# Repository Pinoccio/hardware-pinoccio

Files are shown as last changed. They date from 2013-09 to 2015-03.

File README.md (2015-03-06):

pinoccio-hardware-reference
===========================

Contained are the schematics, board layout, data sheets, and BOM for the
Pinoccio board. The firmware directory also has code for the 16u2 chip
on the board and the booloader running in the main MCU.

For the firmware, the branches contain only the source files. The
compiled versions used in production can be found in the tagged
revisions only.

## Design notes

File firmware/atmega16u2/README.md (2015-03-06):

Pinoccio 16u2 firmware
----------------------

To compile, go into lufa-100807/Projects/arduino-usbserial and run
`make`.

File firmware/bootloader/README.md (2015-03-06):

Pinoccio bootloader
===================
To compile, make sure that you have avr-gcc and friends in your path and
run:

	$ make

This should compile the uracoli lib (for radio / OTA updating) and the
main bootloader. The produced bootloader.hex can be uploaded through
avrdude normally, or through the IDE by putting it in the right place
(see boards.txt for the filename to use).

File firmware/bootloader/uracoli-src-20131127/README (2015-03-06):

This is the uracoli source code package. It contains
the following files:

- +src/+
  Source code of radio and ioutil library.
- +inc/+
  The header files for the libraries.
- +xmpl/+
  Some example applications, that illustrate how to use
  the µracoli functions.
- +wuart+
  The wireless UART application.
- +wibo/+
  The wireless bootloader framework, host application and
  examples.
- +sniffer/+
  The source code of the IEEE 802.15.4 sniffer firmware.
- +doc/+
  User documentation.
- +LICENSE+
  A copy of the uracoli license terms.
- +RELEASENOTES+
  Release history.

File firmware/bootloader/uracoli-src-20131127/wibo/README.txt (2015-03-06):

= WiBo - The Wireless Bootloader  =
:author: Daniel Thiele, Axel Wachtler
:date: 2010/07 - 2012/11
:toc: 1

== Abstract ==

The following article describes the usage of the uracoli wireless bootloader.
WiBo works like a regular bootloader, except that it uses the radio transceiver
instead of a UART. WiBo modifies the flash directly, therefore no special
backup flash memory, like in other over the air upgrade (OTA) solutions,
is required on the transceiver board.

== Concept ==

The WiBo framework provides a method to program the MCU that controls the
transceiver.
Three components are involved,

 * a PC with USB or serial interface, running the  script wibohost.py,
 * a host node, running with the wibohost firmware and
 * the network nodes that have the bootloader installed.

The python script +wibohost.py+ sends a hexfile +app.hex+ in slices
to the host node. It transmits these data slices as unicast or
broadcast frames to the network nodes. The network nodes collect
the data slices and programm them with SPM (self programming mode)
commands in the flash application section of the microcontroller.

In order to verfify if a node was programmed correctly, the
host and network nodes calculate a CRC16 during the transmission and
reception of the data slices.
When programming is completed, the wibohost can query the CRC
from the nodes and compare with its own checksum.

["ditaa"]
---------------------------------------------------------------------
                                             ^
  +------------------+                       | +---------+
  |   +---------+    |                       +-+ Node #1 |
  |   | app.hex |    |                         +---------+
  |   |      {d}|    |         +------+  ^
  |   +---------+    |         | WiBo |  |     ^
  |       |          |    +----* Host +--+     | +---------+
  |       v          |    |    | Node |        +-+ Node #2 |
  | /-------------+  |    |    +------+          +---------+
  | | wibohost.py |->*----+
  | |             |  | serial IF                ^
  | +-------------+  |                          | +---------+
  |                  |                          +-+ Node #3 |
  |                  |                            +---------+
  |       PC         |
  |                  |                        ^
  |                  |                        | +---------+
  +------------------+                        +-+ Node #N |
                                                +---------+
---------------------------------------------------------------------

The bootloading can be done either in *unicast* mode or in *broadcast* mode.
In unicast mode one node is programmed with a program image at one time. In
broadcast mode, multiple nodes receive the image in parallel. This is useful for
programming multiple instances of identical hardware with a firmware image.

.The host site
consists of a http://www.python.org[Python] script and the host node that runs
the wibohost firmware. The script +wibohost.py+ uses the module
http://pyserial.sourceforge.net[pyserial] for serial communication with the host
node. It reads and parses the given hex file and transfers it in slices to the
host node. The host node firmware sends this slices in frames to one (unicast)
or all (broadcast) network nodes.

.The wireless bootloader
resides in bootloader section of the network nodes and occupy about 1K words of
programm memory. Additionally to the bootloader code, configuration record at
the end of the bootloader section. This record ensures that the node address and
channel information is available, even if the EEPROM was accidentely erased.

The network nodes are passive, that means they never send anything if not
queried by the host node.

== Radio Configuration ==

Before the Atmel radio transceivers can be used in a wireless network szenario,
they need to be configured with some key parameters.

The most important parameter is the radio channel, e.g. the frequency on which
the radios communicate. Depending of the radio type, the cannel can be 11 - 26
for the 2.4GHz radios and 0 - 10 for the 868/900 MHz radios. Which channel to
choose depends on the area where the network is operated (for 868/900 MHz) and
which other interferers are present (e.g. Bluetooth and WLAN for 2.4GHz). Since
this topic can't be covered here complete, consult other information sources for
selecting a radio channel to operate on.

Other important parameters are the node address and the network address.
The IEEE-802.15.4 radios support a 16 bit (SHORT-ADDRESS) and a 64 bit
(IEEE-ADDRESS) node address as well as a 16 bit network identifier (PAN-ID).

Since for bootloaders with the limited amount of programm memory no complex
search and asociation procedures can be implemented, the channel and addressing
parameters needs to be stored persistently in the Flash or EEPROM memory of the
network node.

Since the EEPROM in AVR controllers can be easily erased or modified by the
application, a safe place to store  the radio configuration is the flash memory
(the programm memory itself). Since the parameters should be accessible from the
bootloader and from the final application, a so called configuration record is
stored at the end of the flash memory.

In order to create the config record at the flash end, a Intel Hex file needs to
be generated, that is flashed with the hardware programmer and .e.g. with the
tool avrdude.

For generating config records for multiple nodes, the pythonscript +wibo/nodeaddr.py+
is used. Basically the tool can be used directly on the command line.

------
$python wibo/nodeaddr.py -B rdk230 -c 17 -a 1 -A 0x1234567890ABCDEF -p 0xcafe -o foo.hex
Use Parameters:
 board:      rdk230
 addr_key:   1
 group_key:  None
 short_addr: 0x0001
 pan_id:     0xcafe
 ieee_addr:  0x1234567890abcdef
 channel:    17
 offset:     0x0001fff0
 infile:     None
 outfile:    foo.hex
------

More detailed information about the tools options are displayed with the command
------
$python wibo/nodeaddr.py -h
------

As you see in the above example a command line that covers all relevant
parameters is very long and therefore error prone too. The script +nodeaddr.py+
can read its parameters also from a configuration file.

A initial nnotated config file for a network setup is created with the command:

------
$python wibo/nodeaddr.py -G mynetwork.cfg
generated file mynetwork.cfg
$cat mynetwork.cfg
# In the "groups" section several nodes can be configured to be in one group,
# e.g. 1,3,4,5 are ravenboards.
#[group]
#ravengang=1,3:5
....
------

Assuming that your network consists just of rdk230 boards, the file
+mynetwork.cfg+ for the above command line would look so:
------
[board]
default = rdk230

[channel]
default=17

[pan_id]
default=42

[ieee_addr]
0=0x1234567890abcdef

[firmware]
outfile = node_<saddr>.hex
------

The HEX files for the nodes are generated with the next command:

------
$python wibo/nodeaddr.py -C mynetwork.cfg -a 0
$python wibo/nodeaddr.py -C mynetwork.cfg -a 1
------

or in very freaky pipeline way:

------
$python wibo/nodeaddr.py -Cmynetwork.cfg -a0 -o- | avrdude <OPTIONS> -U fl:w:-:i
------

== The Host Application ==

.Compiling and Flashing

Here is an example for the Raven USB Stick. Applying the configuration record
to the hex-file is done in the same manner as for the bootloader application.

----
cd wibo
make -C ../src rzusb
make -f wibohost.mk rzusb
python nodeaddr.py -a 0 -p 1 -c 11 -f ../bin/wibohost_rzusb.hex -B rzusb -o h.hex
avrdude -P usb -c jtag2 -p at90usb1287 -U h.hex
----

.Note:
The option "-p 1" set the IEEE PAN_ID to "1" and must be identical
for the bootloader application and the wibohost application.

== Python Host Application ==

.Using wibohost.py

To test the wireless bootloader environment, the xmpl_wibo application will be
used. It blinks a LED with a certain frequency and is able to  jump in the
bootloader when the special "jump_to_bootloader" frame is received.

At first create some firmware versions, e.g. one slow and one fast
blinking. The network nodes shall be rdk230 nodes.
----
make -f xmpl_wibo.mk BLINK=0x7fffUL TARGET=slow rdk230
make -f xmpl_wibo.mk BLINK=0xffffUL TARGET=fast rdk230
----

Next assume that you have 4 network nodes with addresses [1,2,3,4].
In order to check the presence of the nodes, run the scan command.

-----
python wibohost.py -P COM1 -S
-----

Note that the default address range of wibohost.py is 1 ... 8. This can be modified with the -A option. In the example above, only the nodes 1 to 4
are present, therefore no response from the nodes 5 ... 8 is received.

At first we update all nodes with the slow blinking firmware. Therefore we use the broadcast mode (-U),
that means that the image is transfered only once over the air. The address range (-A) is needed to
ping the nodes before programming and afterwards to verify their CRC.

-----
python wibhost.py -P COM1 -A1:4 -U slow.hex
-----

In the next step we selectively flash node 1 and node 3 with the file fast.hex. Since we use unicast
programming (-u), the image is transfered for each node over the air seperately.

-----
python wibhost.py -P COM1 -A1,3 -u fast.hex
-----

== The Bootloader Application ==

.Build and Flash

Build the bootloader for your board with the command
----
make -C ../src <board>
make -f wibo.mk <board>
----

With the command +make -f wibo.mk list+ the available <board>s are displayed.

The bootloader expects an address record at the end of the flash memory section.
This record can be generated with the script nodeaddr.py. Here is an example for
the rdk230 board.

-----
# generate a hex file with the configuration record for node #1
python nodeaddr.py -a 1 -p 1 -c 11 \
       -f ../bin/wibo_rdk230.hex -B rdk230 -o a1.hex

# flash node #1 (SHORT_ADDR=1)
avrdude -P usb -p m1281 -c jtag2 -U a1.hex

# Fuses for initial jump to bootloader
avrdude -P usb -p m1281 -c jtag2 -U lf:w:0xe2:m \
        -U hf:w:0x98:m -U ef:w:0xff:m
-----

To verify the correct AVR fuse settings refer to http://www.engbedded.com/fusecalc.

To flash multiple nodes more efficiently, the nodeaddr.py can pipe its output
directly into avrdude. This slightly more complex command line
can be stored in script +flashwibo.sh+ (under Windows replace $1 by %1
for +flashwibo.bat+):

[name="flashwibo.sh"]
----
python nodeaddr.py -a $1 -p 1 -c 11 -f ../bin/wibo_rdk230.hex -B rdk230 |\
       avrdude -P usb -p m1281 -c jtag2 \
                -U fl:w:-:i -U lf:w:0xe2:m -U hf:w:0x98:m -U ef:w:0xff:m
----

.Note:
The option "-p 1" set the IEEE PAN_ID to "1" and must be identical
for the bootloader application and the wibohost application.

With the +python nodeaddr.py -h+ the help screen is displayed.

.Flash memory partitioning

The AVR flash memory can be divided in an application and a booloader
section. The application section is located in the lower address memory.
The bootloader section is located in the upper flash memory. In this
section the so called self programming opcodes (SPM) can be executed by
the AVR core. This SPM opcodes allows erasing and reprogramming the
application flash memory.

["ditaa"]
---------------------------------------------------------------------
 +--------------------------------+ <----FLASH_END
 |  Config Record                 |
 |--=-----------------------------|
 |                                |
 | Bootloader Section             |
 |                                |
 +--------------------------------+ <----BOOTLOADER_OFFSET
 |                                |
 |                                |
 |                                |
 |                                |
 |                                |
 | Application Section            |
 |                                |
 +--------------------------------+ <-----0x0000
---------------------------------------------------------------------

The start address of the bootloader section is determined by the BOOTLSZ
fuse bits. The BOOTRST fuse bit determines, if the AVR core jumps after
reset to the application section (address 0x0000) or to the bootloader
section (e.g. address 0xf000). The AVR fuse bits and the content of the
bootloader section can only be changed either by ISP, JTAG or High Voltage
programming.

In order to have enough memory for the application available, the booloader
section is choosen to be rather small, e.g. for 8K devices a 1K bootloader
section and 7K application section is a reasonable choice. The larger 128k
AVR devices are partitioned usually with a 4K bootloader section, leaving
124K flash memory for the application.

.The Configuration Record at FLASH_END

For WiBo, the last 16 byte of the flash memory are reserved for a configuration
record, that holds address and channel parameters, which are needed for
operation. The structure of this record is defined in file +board.h+ in the type
+node_config_t+. It stores

 - 2 byte SHORT_ADDRESS
 - 2 byte PAN ID
 - 8 byte IEEE_ADDRESS
 - 1 byte channel hint
 - 2 reserved bytes
 - 2 byte CRC16

 The configuration record is accessible from the applicatation and from the bootloader section.

== The WiBoHost API ==

The file wibohost.py can also be used as a python module. The following
script shows how a broadcast and a unicast flash can be programmed.

-----
from wibohost import WIBOHost

wh = WIBOHost()
# open serial connection to wibohost node
wh.close()
wh.setPort("COM19")
wh.setBaudrate(38400)
wh.setTimeout(1)
wh.open()
# check if local echo works.
print WHOST.echo("The quick brown fox jumps")

# scan addresses 1 to 4
addr_lst = wh.scan(range(1,4+1))

# broadcast mode, flash all nodes
for n in addr_lst:
    wh.xmpljbootl(n)
    print "PING  :", n, wh.ping(n)

print "FLASH :", wh.flashhex(0xffff, "foo.hex")
for n in addr_lst:
    print "CRC  :", n, wh.checkcrc(n)
    print "EXIT :", n, wh.exit(n)

# unicast mode, flash node 1
wh.xmpljbootl(1)
print "PING  :#1", wh.ping(1)
print "FLASH :#1", wh.flashhex(1, "bar.hex")
print "CRC   :#1", wh.checkcrc(1)
print "EXIT  :#1", wh.exit(1)
-----

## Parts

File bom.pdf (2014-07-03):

P1000 BILL OF MATERIALS

Name | ID | Package | Reel Width Qty | Layout Name

MCU Section
Microcontroller | ATmega256RFR2-ZU | QFN-64 | 16mm | 1 U4
Microcontroller | ATmega16U2-MU | QFN-32 | 12mm | 1 U3
Crystal 16MHz | Tellurian 3960A 16MHz | 4-SMD, No Lead (DFN, LCC) 8mm | 2 X1,X3
Crystal 32.768kHz | Tellurian 3960B 32.768k | 2-SMD | 8mm | 1 X2

RF Section
Balun | 2450BM15A0015E | 0805 | 8mm | 1 B1
Chip antenna | 2450AT43A100E | SMT | 10mm | 1 Y1

Power Section
3.3v regulator | TPS78233DDCT | SOT 23-5 | 8mm | 1 U2
Li-Ion/Li-Poly charger | MCP73832 | SOT 23-5 | 8mm | 1 U1
Fuel Gauge | MAX17048G+ | TDFN-8 | 8mm | 1 U5
Ferrite chip | MPZ1608S221A | 0603 | 8mm | 1 L1
Varistor | CG0402MLC-05LG | 0402 | 8mm | 2 R2,R13
SPDT power switch | AYZ0102AGRLC | SMT | 16mm | 1 S1
USB micro B jack | UB-MC5BR3-SD204-4S-1 | SMT right-angle, horizontal 16mm | 1 USB-JACK
Single load switch | SIP32431DNP3-T1GE4TR-ND | TDFN4 | 8mm | 2 U6,U7
JST SFH male battery jack | SM02B-SFHRS-TF(LF)(SN) | SMT right-angle | 12mm | 1 JST
Schottky diode | CDBU0520 | 0603 | 8mm | 1 D3
MOSFET P-Channel | SI2305CDS | SOT 23-3 | 8mm | 1 Q1

Miscellaneous
0 ohm resistor | ERJ-2GE0R00X | 0402 | 8mm | 1 R24
22 ohm resistor | ERJ-2GEJ220X | 0402 | 8mm | 2 R9,R10
470 ohm resistor | ERJ-2GEJ471X | 0402 | 8mm | 6 R3,R6,R11,R12,R14,R18
1k ohm resistor | ERJ-2GEJ102X | 0402 | 8mm | 4 R7,R8,R15,R17,
2k ohm resistor | ERJ-2GEJ202X | 0402 | 8mm | 5 R1,R4,R16,R22,R23
100k ohm resistor | ERJ-2GEJ104X | 0402 | 8mm | 3 R5,R19,R20
4.7nH inductor | LQG15HS4N7S02D | 0402 | 8mm | 1 L2
1.0 pf capacitor | C1005C0G1H010C | 0402 | 8mm | 2 C9,C23
10 pf capacitor | C1005C0G1H100D050BA | 0402 | 8mm | 4 C12,C13,C16,C17
12 pf capacitor | C1005C0G1H120J | 0402 | 8mm | 2 C14,C15
0.1 uf capacitor | C1005X5R1A104K | 0402 | 8mm | 2 C3,C19
1.0 uf capacitor | C1005X5R0J105M | 0402 | 8mm | 4 C6,C7,C8,C18
2.2 uf capacitor | C1005X5R0J225M | 0402 | 8mm | 2 C2,C11
4.7 uf capacitor | C1005X5R0J475K | 0402 | 8mm | 2 C4,C5
LED green | HSMG-C190 | 0603 | 8mm | 1 D1
LED yellow | HSMY-C190 | 0603 | 8mm | 1 D2
LED RGB | CLVBA-FKA-CAEDH8BBB7A363 4-PLCC | 8mm | 1 U8
Female headers 2mm - low profile BCSS-216-S-02-GT-LF | Through-hole | 2 JP-L,JP-R

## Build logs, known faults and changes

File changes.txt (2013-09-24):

------------------------------------------------------------------------
- v0.13 - 2013-06-28
------------------------------------------------------------------------
- Put silkscreen for switch and battery jacks on bottom of board
- Move headers out 15 mils each
- Move RGB LED and lower ISP pads up
- Add 2k pull-up resistor to backpack bus
- Add 2k pull-up resistors to SDA/SCL

------------------------------------------------------------------------
- v0.12 - 2013-06-27
------------------------------------------------------------------------
- Add schottky diode between power load switch input and VUSB--was causing
  the P-channel MOSFET from fully enabling after plugging in USB then
  unplugging it
- Remove voltage divider circuit from Lipo charge status pin to CHGSTATUS
- Changed load switch/MOSFET pull-down resistor to 100k with diode fix

------------------------------------------------------------------------
- v0.11 - 2013-04-27
------------------------------------------------------------------------
- Tie battery header pin to VBAT, not VBAT-AS
- Remove AREF with a 100nF cap, turns out datasheet does not require it
- Decrease pull-down resistor value for gate of P-channel MOSFET to 1k
- Add voltage divider for charge enabled pin to the RFR2
- Tie anode of serial LED to UCAP on 16U2, instead of VUSB
- Add load switch to anode of RGB LED
- Swap D8 and BATTALRT pins so BATTALRT can externally interrupt the
  MCU from the deepest sleep states on low-battery

------------------------------------------------------------------------
- v0.10 - 2013-03-29
------------------------------------------------------------------------
- Add MOSFET/Load Switch pair to fix charge controller oscillation
- 16U2 sometimes started in DFU mode, tied 16U2 reset pin to VUSB, not VCC
- Switch to MCP73832 charge controller for open-drain status pin
- Change silkscreen to start GPIOs with D2 instead of D0, like Arduino
- Add 470Ω resistor to reset header pin, as direct can exceed voltage spec
- Moved to a single load switch for 3V3 header pin, leaving VBAT direct
- Add a 100k pull-down resistor to the ON pin of the load switch
- Tie pin 2 of 16U2 ICSP pin to UCAP, not VCC, for programming ability
  with switch off
- Decouple AREF with a 100nF cap, per Atmel app note suggestion
- Add dedicated shield identification pin, called the "Backpack Bus"
- Replace voltage divider battery check circuit with MAX17048 fuel gauge
- Add RF pi network for RF prescreen preparation and tuning if necessary

------------------------------------------------------------------------
- v0.9 - 2012-12-26
------------------------------------------------------------------------
- Replace the CAT6219 LDO regulator with a TPS78233, for much lower
  quiescent current (55µA vs 0.5µA)
- Replace the dual MOSFET package with a TPS22960 dual load switch
- Swap several header pins for better layout
- Move RGB LED down a few mils for better layout
- Add ability to switch off header pin 3V3 via MCU pin PD5
- Change ISP pads on bottom to be full 0.1" pitch, for easier pogopin use
- Add ATmega16U2 10k pullup resistor on reset line

------------------------------------------------------------------------
- v0.7 - 2012-11-17
------------------------------------------------------------------------
- Add ATmega16U2 for full Arduino support
- Add MOSFET-based battery voltage check
- Update header legends to reflect pinout changes
- Add RGB LED to board
- Migrate all 0402 landing patterns to smaller, round-cornered ones to
  minimize tombstoning during production

------------------------------------------------------------------------
- v0.6 - 2012-10-03
------------------------------------------------------------------------
- Initial release

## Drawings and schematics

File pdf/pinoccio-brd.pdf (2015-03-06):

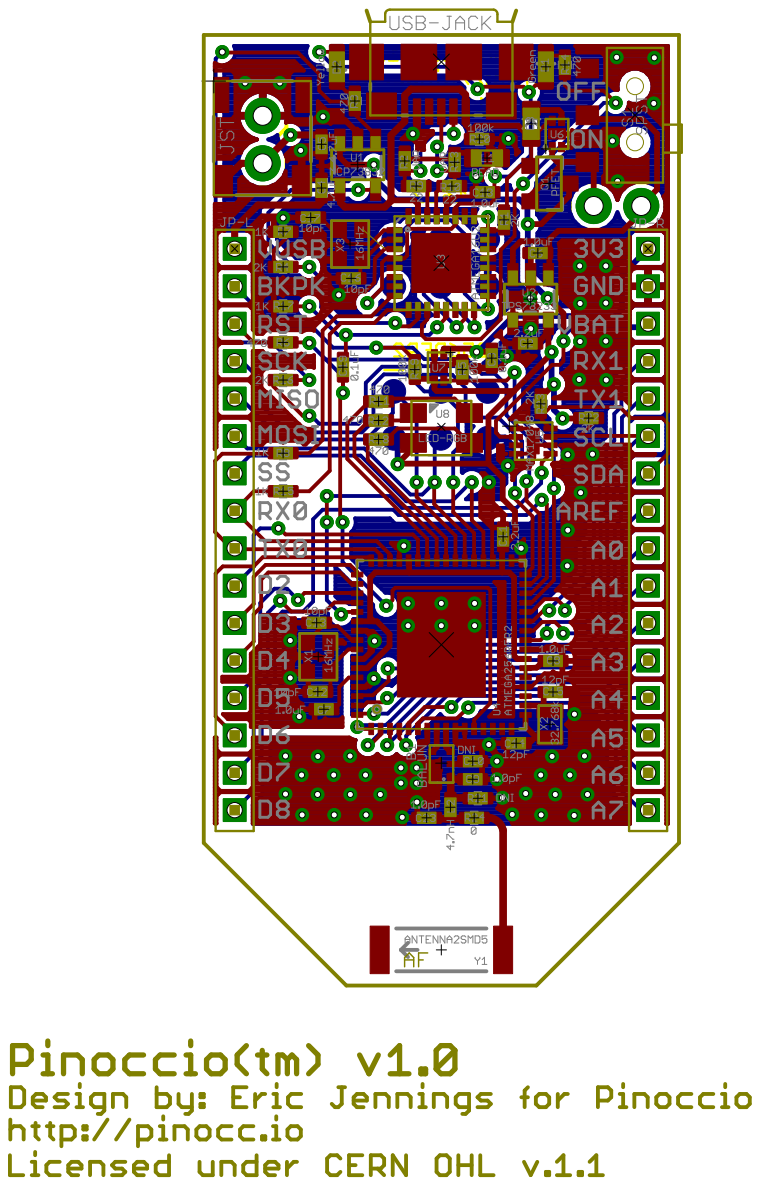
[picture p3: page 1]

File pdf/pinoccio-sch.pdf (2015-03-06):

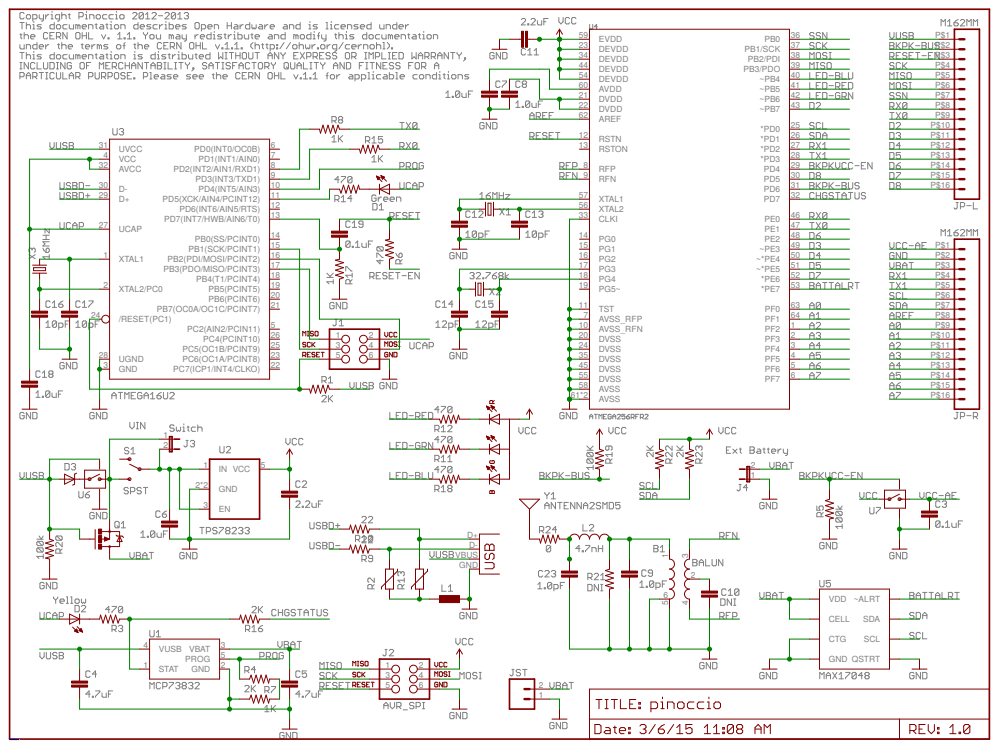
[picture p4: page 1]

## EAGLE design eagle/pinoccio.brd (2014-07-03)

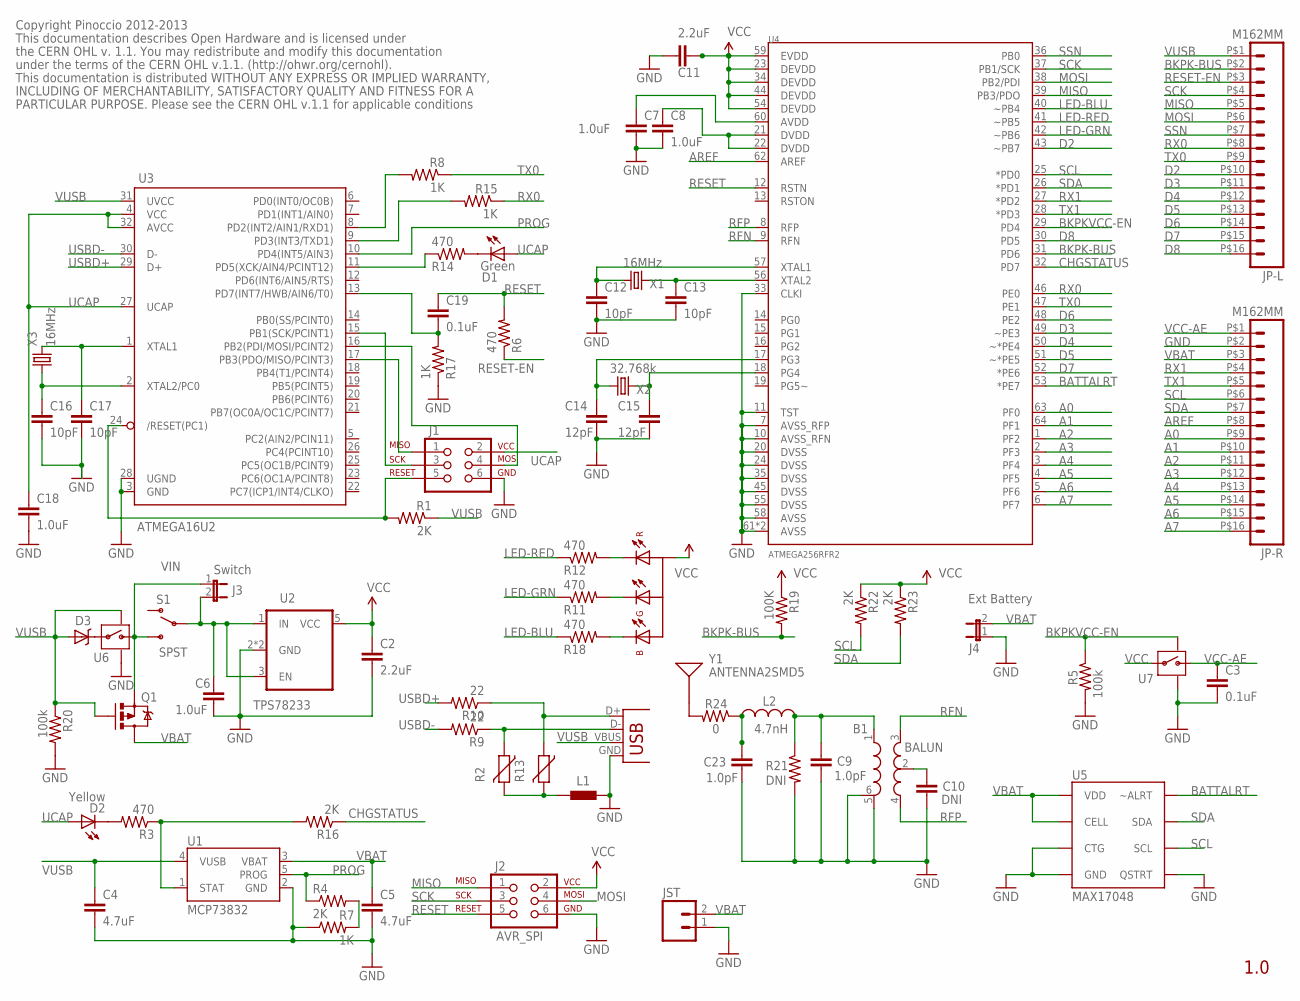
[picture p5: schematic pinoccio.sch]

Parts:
B1: BALUN
C2, C11: 2.2uF; 0402-CAP
C3, C19: 0.1uF; 0402-CAP
C4, C5: 4.7uF; 0402-CAP
C6, C7, C8, C18: 1.0uF; 0402-CAP
C9, C23: 1.0pF; 0402-CAP
C10: DNI; 0402-CAP
C12, C13, C16, C17: 10pF; 0402-CAP
C14, C15: 12pF; 0402-CAP
D1: Green; LED-0603
D2: Yellow; LED-0603
D3: DIODE-SCHOTTKY; 0603-DIODE
J1: AVR_SPI_PRG_6; 2X3-PAD
J2: AVR_SPI; 2X3-PAD
J3: Switch; 1X02
J4: Ext Battery; 1X02
JP-L: M162MM; 1X16_2MM
JP-R: M162MM; 1X16_2MM
JST: M02JST-SFH; JST-SFH
L1: BEAD; 0603
L2: 4.7nH; 0402-CAP
Q1: PFET; SOT23-3
R1, R4, R16, R22, R23: 2K; 0402-RES
R2, R13: VAR; 0402
R3, R6, R11, R12, R14, R18: 470; 0402-RES
R5, R20: 100k; 0402-RES
R7, R8, R15, R17: 1K; 0402-RES
R9, R10: 22; 0402-RES
R19: 100K; 0402-RES
R21: DNI; 0402-RES
R24: 0; 0402-RES
S1: SPST; SWITCH-SPDT-SMD
U1: MCP73832; SOT23-5
U2: TPS78233; SOT23-5
U3: ATMEGA16U2; QFN-32
U4: ATMEGA256RFR2; QFN-64
U5: MAX17048; DFN-8
U6, U7: SWITCH; TDFN4
U8: LED-RGB; PLCC4
USB-JACK: USB-MICROB
X1, X3: 16MHz; CRYSTAL-SMD-2.5X2-ABM10
X2: 32.768k; CRYSTAL-SMD-2X1.2-ABS06
Y1: ANTENNA2SMD5; ANTENNA-CHIP5

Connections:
A0: JP-R.P$9 (9), U4.63 (PF0)
A1: JP-R.P$10 (10), U4.64 (PF1)
A2: JP-R.P$11 (11), U4.1 (PF2)
A3: JP-R.P$12 (12), U4.2 (PF3)
A4: JP-R.P$13 (13), U4.3 (PF4)
A5: JP-R.P$14 (14), U4.4 (PF5)
A6: JP-R.P$15 (15), U4.5 (PF6)
A7: JP-R.P$16 (16), U4.6 (PF7)
AREF: JP-R.P$8 (8), U4.62 (AREF)
BATTALRT: U4.53 (*PE7), U5.P$5 (~ALRT)
BKPK-BUS: JP-L.P$2 (2), R19.2, U4.31 (PD6)
BKPKVCC-EN: R5.1, U4.29 (PD4), U7.P$4 (ON)
CHGSTATUS: R16.1, U4.32 (PD7)
D2: JP-L.P$10 (10), U4.43 (~PB7)
D3: JP-L.P$11 (11), U4.49 (~PE3)
D4: JP-L.P$12 (12), U4.50 (~*PE4)
D5: JP-L.P$13 (13), U4.51 (~*PE5)
D6: JP-L.P$14 (14), U4.48 (PE2)
D7: JP-L.P$15 (15), U4.52 (*PE6)
D8: JP-L.P$16 (16), U4.30 (PD5)
GND: B1.5 (GND), B1.6 (GND), C2.2, C3.2, C4.2, C5.2, C6.2, C7.2, C8.2, C9.2, C10.2, C11.2, C12.2, C13.2, C14.2, C15.2, C16.2, C17.2, C18.2, C23.2, J1.6, J2.6, J4.1, JP-R.P$2 (2), JST.1, L1.1, R5.2, R7.1, R17.1, R20.2, R21.2, U1.2 (GND), U2.2 (GND), U2.4 (GND), U3.3 (GND), U3.28 (UGND), U4.7 (AVSS_RFP), U4.10 (AVSS_RFN), U4.11 (TST), U4.20 (DVSS), U4.24 (DVSS), U4.33 (CLKI), U4.35 (DVSS), U4.45 (DVSS), U4.55 (DVSS), U4.58 (AVSS), U4.61 (AVSS), U4.PADDLE (AVSS), U5.P$1 (CTG), U5.P$4 (GND), U5.P$6 (QSTRT), U5.P$9 (GND), U6.P$2 (GND), U6.P$5 (GND), U7.P$2 (GND), U7.P$5 (GND), USB-JACK.GND, X1.P$2 (GND), X1.P$4 (GND), X3.P$2 (GND), X3.P$4 (GND)
LED-BLU: R18.1, U4.40 (~PB4)
LED-GRN: R11.1, U4.42 (~PB6)
LED-RED: R12.1, U4.41 (~PB5)
MISO: J2.1, JP-L.P$5 (5), U4.39 (PB3/PDO)
MOSI: J2.4, JP-L.P$6 (6), U4.38 (PB2/PDI)
unnamed: R12.2, U8.P$1 (R-C)
unnamed: R2.1, R9.1, USB-JACK.D-
unnamed: D3.C, U6.P$3 (IN)
unnamed: B1.1 (IN), C9.1, L2.1, R21.1
unnamed: R11.2, U8.P$4 (G-C)
unnamed: R18.2, U8.P$3 (B-C)
unnamed: J1.5, R1.2, U3.24 (/RESET(PC1))
unnamed: R4.2, R7.2
unnamed: L1.2, R2.2, R13.2
unnamed: C7.1, U4.60 (AVDD)
unnamed: R3.1, R16.2, U1.1 (STAT)
unnamed: B1.2 (RFGND), C10.1
unnamed: C12.1, U4.57 (XTAL1), X1.P$1 (1)
unnamed: C13.1, U4.56 (XTAL2), X1.P$3 (2)
unnamed: C14.1, U4.17 (PG3), X2.P$1 (1)
unnamed: C15.1, U4.18 (PG4), X2.P$2 (2)
unnamed: C16.1, U3.2 (XTAL2/PC0), X3.P$1 (1)
unnamed: C8.1, U4.21 (DVDD), U4.22 (DVDD)
unnamed: C17.1, U3.1 (XTAL1), X3.P$3 (2)
unnamed: D2.C, R3.2
unnamed: C19.2, R17.2, U3.13 (PD7(INT7/HWB/AIN6/T0))
unnamed: R15.2, U3.9 (PD3(INT3/TXD1))
unnamed: R8.2, U3.8 (PD2(INT2/AIN1/RXD1))
unnamed: C23.1, L2.2, R24.1
unnamed: R24.2, Y1.FEED
unnamed: R10.1, R13.1, USB-JACK.D+
unnamed: J3.1, Q1.2 (S), S1.3 (S), U6.P$1 (OUT)
unnamed: J1.1, U3.17 (PB3(PDO/MISO/PCINT3))
unnamed: J1.4, U3.16 (PB2(PDI/MOSI/PCINT2))
unnamed: J1.3, U3.15 (PB1(SCK/PCINT1))
unnamed: R14.1, U3.11 (PD5(XCK/AIN4/PCINT12))
unnamed: D1.C, R14.2
PROG: R4.1, U1.5 (PROG), U3.10 (PD4(INT5/AIN3))
RESET: C19.1, J2.5, R6.2, U4.12 (RSTN)
RESET-EN: JP-L.P$3 (3), R6.1
RFN: B1.3 (OUT1), U4.9 (RFN)
RFP: B1.4 (OUT2), U4.8 (RFP)
RX0: JP-L.P$8 (8), R15.1, U4.46 (PE0)
RX1: JP-R.P$4 (4), U4.27 (*PD2)
SCK: J2.3, JP-L.P$4 (4), U4.37 (PB1/SCK)
SCL: JP-R.P$6 (6), R22.2, U4.25 (*PD0), U5.P$7 (SCL)
SDA: JP-R.P$7 (7), R23.2, U4.26 (*PD1), U5.P$8 (SDA)
SSN: JP-L.P$7 (7), U4.36 (PB0)
TX0: JP-L.P$9 (9), R8.1, U4.47 (PE1)
TX1: JP-R.P$5 (5), U4.28 (*PD3)
UCAP: C18.1, D1.A, D2.A, J1.2, U3.4 (VCC), U3.27 (UCAP), U3.32 (AVCC)
USBD+: R10.2, U3.29 (D+)
USBD-: R9.2, U3.30 (D-)
VBAT: C5.1, J4.2, JP-R.P$3 (3), JST.2, Q1.3 (D), U1.3 (VBAT), U5.P$2 (CELL), U5.P$3 (VDD)
VCC: C2.1, C11.1, J2.2, R19.1, R22.1, R23.1, U2.5 (VCC), U4.23 (DEVDD), U4.34 (DEVDD), U4.44 (DEVDD), U4.54 (DEVDD), U4.59 (EVDD), U7.P$3 (IN), U8.P$2 (A)
VCC-AE: C3.1, JP-R.P$1 (1), U7.P$1 (OUT)
VIN: C6.1, J3.2, S1.2, U2.1 (IN), U2.3 (EN)
VUSB: C4.1, D3.A, JP-L.P$1 (1), Q1.1 (G), R1.1, R20.1, U1.4 (VUSB), U3.31 (UVCC), U6.P$4 (ON), USB-JACK.VBUS

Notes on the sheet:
1.0
Copyright Pinoccio 2012-2013
This documentation describes Open Hardware and is licensed under
the CERN OHL v. 1.1. You may redistribute and modify this documentation
under the terms of the CERN OHL v.1.1. (http://ohwr.org/cernohl).
This documentation is distributed WITHOUT ANY EXPRESS OR IMPLIED WARRANTY,
INCLUDING OF MERCHANTABILITY, SATISFACTORY QUALITY AND FITNESS FOR A
PARTICULAR PURPOSE. Please see the CERN OHL v.1.1 for applicable conditions

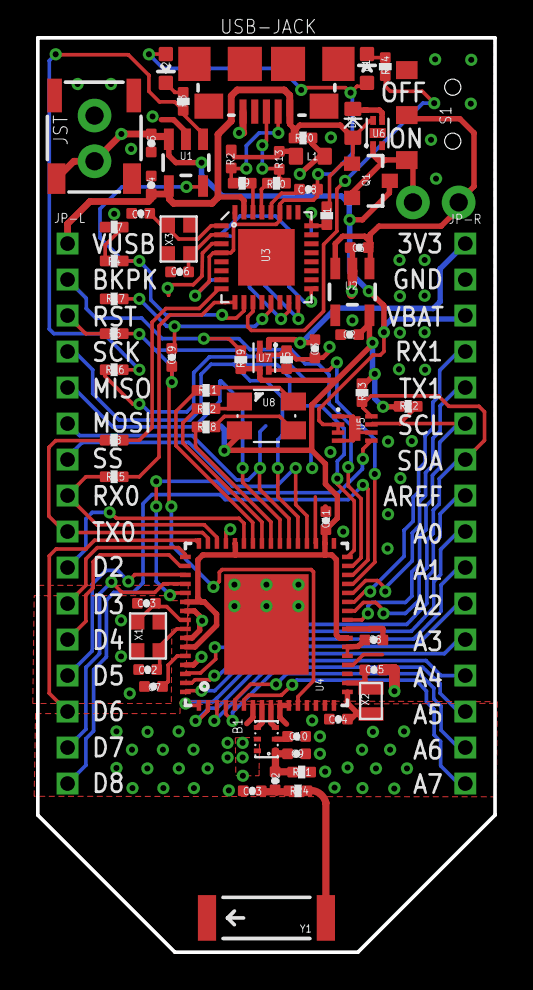
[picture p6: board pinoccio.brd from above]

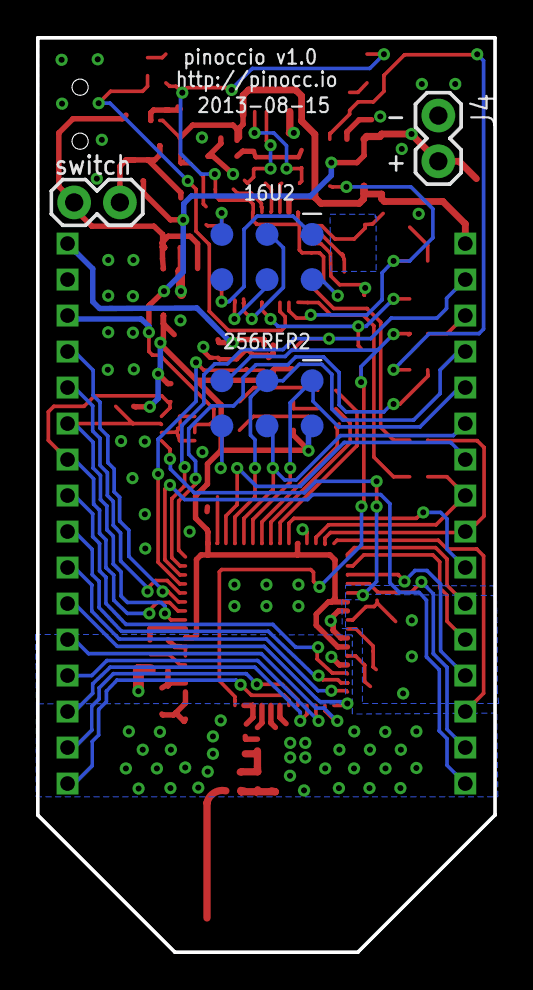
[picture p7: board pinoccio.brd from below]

Board: 2 copper layers, 25.4 x 50.8 mm, 71 parts (4 on the bottom side), 79 nets.

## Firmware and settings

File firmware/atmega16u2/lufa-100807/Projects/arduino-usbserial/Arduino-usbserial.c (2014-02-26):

/*
             LUFA Library
     Copyright (C) Dean Camera, 2010.
              
  dean [at] fourwalledcubicle [dot] com
      www.fourwalledcubicle.com
*/

/*
  Copyright 2010  Dean Camera (dean [at] fourwalledcubicle [dot] com)

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
  The author disclaim all warranties with regard to this
  software, including all implied warranties of merchantability
  and fitness.  In no event shall the author be liable for any
  special, indirect or consequential damages or any damages
  whatsoever resulting from loss of use, data or profits, whether
  in an action of contract, negligence or other tortious action,
  arising out of or in connection with the use or performance of
  this software.
*/

/** \file
 *
 *  Main source file for the Arduino-usbserial project. This file contains the main tasks of
 *  the project and is responsible for the initial application hardware configuration.
 */

#include "Arduino-usbserial.h"

/** Circular buffer to hold data from the host before it is sent to the device via the serial port. */
RingBuff_t USBtoUSART_Buffer;

/** Circular buffer to hold data from the serial port before it is sent to the host. */
RingBuff_t USARTtoUSB_Buffer;

/** Pulse generation counters to keep track of the number of milliseconds remaining for each pulse type */
volatile struct
{
	uint8_t TxLEDPulse; /**< Milliseconds remaining for data Tx LED pulse */
	uint8_t RxLEDPulse; /**< Milliseconds remaining for data Rx LED pulse */
	uint8_t PingPongLEDPulse; /**< Milliseconds remaining for enumeration Tx/Rx ping-pong LED pulse */
} PulseMSRemaining;

/** LUFA CDC Class driver interface configuration and state information. This structure is
 *  passed to all CDC Class driver functions, so that multiple instances of the same class
 *  within a device can be differentiated from one another.
 */
USB_ClassInfo_CDC_Device_t VirtualSerial_CDC_Interface =
	{
		.Config = 
			{
				.ControlInterfaceNumber         = 0,

				.DataINEndpointNumber           = CDC_TX_EPNUM,
				.DataINEndpointSize             = CDC_TXRX_EPSIZE,
				.DataINEndpointDoubleBank       = false,

				.DataOUTEndpointNumber          = CDC_RX_EPNUM,
				.DataOUTEndpointSize            = CDC_TXRX_EPSIZE,
				.DataOUTEndpointDoubleBank      = false,

				.NotificationEndpointNumber     = CDC_NOTIFICATION_EPNUM,
				.NotificationEndpointSize       = CDC_NOTIFICATION_EPSIZE,
				.NotificationEndpointDoubleBank = false,
			},
	};

/** Main program entry point. This routine contains the overall program flow, including initial
 *  setup of all components and the main program loop.
 */
int main(void)
{
	SetupHardware();
	
	RingBuffer_InitBuffer(&USBtoUSART_Buffer);
	RingBuffer_InitBuffer(&USARTtoUSB_Buffer);

	sei();

	for (;;)
	{
		/* Only try to read in bytes from the CDC interface if the transmit buffer is not full */
		if (!(RingBuffer_IsFull(&USBtoUSART_Buffer)))
		{
			int16_t ReceivedByte = CDC_Device_ReceiveByte(&VirtualSerial_CDC_Interface);

			/* Read bytes from the USB OUT endpoint into the USART transmit buffer */
			if (!(ReceivedByte < 0))
			  RingBuffer_Insert(&USBtoUSART_Buffer, ReceivedByte);
		}
		
		/* Check if the UART receive buffer flush timer has expired or the buffer is nearly full */
		RingBuff_Count_t BufferCount = RingBuffer_GetCount(&USARTtoUSB_Buffer);
		if ((TIFR0 & (1 << TOV0)) || (BufferCount > BUFFER_NEARLY_FULL))
		{
			TIFR0 |= (1 << TOV0);

			if (USARTtoUSB_Buffer.Count) {
				LEDs_TurnOnLEDs(LEDMASK_TX);
				PulseMSRemaining.TxLEDPulse = TX_RX_LED_PULSE_MS;
			}

			/* Read bytes from the USART receive buffer into the USB IN endpoint */
			while (BufferCount--)
			  CDC_Device_SendByte(&VirtualSerial_CDC_Interface, RingBuffer_Remove(&USARTtoUSB_Buffer));
			  
			/* Turn off TX LED(s) once the TX pulse period has elapsed */
			if (PulseMSRemaining.TxLEDPulse && !(--PulseMSRemaining.TxLEDPulse))
			  LEDs_TurnOffLEDs(LEDMASK_TX);

			/* Turn off RX LED(s) once the RX pulse period has elapsed */
			if (PulseMSRemaining.RxLEDPulse && !(--PulseMSRemaining.RxLEDPulse))
			  LEDs_TurnOffLEDs(LEDMASK_RX);
		}
		
		/* Load the next byte from the USART transmit buffer into the USART */
		if (!(RingBuffer_IsEmpty(&USBtoUSART_Buffer))) {
		  Serial_TxByte(RingBuffer_Remove(&USBtoUSART_Buffer));
		  	
		  	LEDs_TurnOnLEDs(LEDMASK_RX);
			PulseMSRemaining.RxLEDPulse = TX_RX_LED_PULSE_MS;
		}
		
		CDC_Device_USBTask(&VirtualSerial_CDC_Interface);
		USB_USBTask();
	}
}

/** Configures the board hardware and chip peripherals for the demo's functionality. */
void SetupHardware(void)
{
	/* Disable watchdog if enabled by bootloader/fuses */
	MCUSR &= ~(1 << WDRF);
	wdt_disable();

	/* Hardware Initialization */
	Serial_Init(9600, false);
	LEDs_Init();
	USB_Init();
	
	/* Set PD4 to Hi-z/input to enable charge controller */
  DDRD & ~(0x01 << 4);
  PORTD & ~(0x01 << 4);
  
	/* Start the flush timer so that overflows occur rapidly to push received bytes to the USB interface */
	TCCR0B = (1 << CS02);
	
	/* Pull target /RESET line high */
	AVR_RESET_LINE_PORT |= AVR_RESET_LINE_MASK;
	AVR_RESET_LINE_DDR  |= AVR_RESET_LINE_MASK;
}

/** Event handler for the library USB Configuration Changed event. */
void EVENT_USB_Device_ConfigurationChanged(void)
{
	CDC_Device_ConfigureEndpoints(&VirtualSerial_CDC_Interface);
}

/** Event handler for the library USB Unhandled Control Request event. */
void EVENT_USB_Device_UnhandledControlRequest(void)
{
	CDC_Device_ProcessControlRequest(&VirtualSerial_CDC_Interface);
}

/** Event handler for the CDC Class driver Line Encoding Changed event.
 *
 *  \param[in] CDCInterfaceInfo  Pointer to the CDC class interface configuration structure being referenced
 */
void EVENT_CDC_Device_LineEncodingChanged(USB_ClassInfo_CDC_Device_t* const CDCInterfaceInfo)
{
	uint8_t ConfigMask = 0;

	switch (CDCInterfaceInfo->State.LineEncoding.ParityType)
	{
		case CDC_PARITY_Odd:
			ConfigMask = ((1 << UPM11) | (1 << UPM10));		
			break;
		case CDC_PARITY_Even:
			ConfigMask = (1 << UPM11);		
			break;
	}

	if (CDCInterfaceInfo->State.LineEncoding.CharFormat == CDC_LINEENCODING_TwoStopBits)
	  ConfigMask |= (1 << USBS1);

	switch (CDCInterfaceInfo->State.LineEncoding.DataBits)
	{
		case 6:
			ConfigMask |= (1 << UCSZ10);
			break;
		case 7:
			ConfigMask |= (1 << UCSZ11);
			break;
		case 8:
			ConfigMask |= ((1 << UCSZ11) | (1 << UCSZ10));
			break;
	}

	/* Must turn off USART before reconfiguring it, otherwise incorrect operation may occur */
	UCSR1B = 0;
	UCSR1A = 0;
	UCSR1C = 0;

	/* Special case 57600 baud for compatibility with the ATmega328 bootloader. */	
	UBRR1  = (CDCInterfaceInfo->State.LineEncoding.BaudRateBPS == 57600)
			 ? SERIAL_UBBRVAL(CDCInterfaceInfo->State.LineEncoding.BaudRateBPS)
			 : SERIAL_2X_UBBRVAL(CDCInterfaceInfo->State.LineEncoding.BaudRateBPS);	

	UCSR1C = ConfigMask;
	UCSR1A = (CDCInterfaceInfo->State.LineEncoding.BaudRateBPS == 57600) ? 0 : (1 << U2X1);
	UCSR1B = ((1 << RXCIE1) | (1 << TXEN1) | (1 << RXEN1));
}

/** ISR to manage the reception of data from the serial port, placing received bytes into a circular buffer
 *  for later transmission to the host.
 */
ISR(USART1_RX_vect, ISR_BLOCK)
{
	uint8_t ReceivedByte = UDR1;

	if (USB_DeviceState == DEVICE_STATE_Configured)
	  RingBuffer_Insert(&USARTtoUSB_Buffer, ReceivedByte);
}

/** Event handler for the CDC Class driver Host-to-Device Line Encoding Changed event.
 *
 *  \param[in] CDCInterfaceInfo  Pointer to the CDC class interface configuration structure being referenced
 */
void EVENT_CDC_Device_ControLineStateChanged(USB_ClassInfo_CDC_Device_t* const CDCInterfaceInfo)
{
	bool CurrentDTRState = (CDCInterfaceInfo->State.ControlLineStates.HostToDevice & CDC_CONTROL_LINE_OUT_DTR);

	if (CurrentDTRState)
	  AVR_RESET_LINE_PORT &= ~AVR_RESET_LINE_MASK;
	else
	  AVR_RESET_LINE_PORT |= AVR_RESET_LINE_MASK;
}

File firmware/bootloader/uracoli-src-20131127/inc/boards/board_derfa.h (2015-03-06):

/* Copyright (c) 2009 - 2013 Daniel Thiele, Eric Gnoske, Axel Wachtler
   All rights reserved.

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
   THIS SOFTWARE IS PROVIDED BY THE COPYRIGHT HOLDERS AND CONTRIBUTORS "AS IS"
   AND ANY EXPRESS OR IMPLIED WARRANTIES, INCLUDING, BUT NOT LIMITED TO, THE
   IMPLIED WARRANTIES OF MERCHANTABILITY AND FITNESS FOR A PARTICULAR PURPOSE
   ARE DISCLAIMED. IN NO EVENT SHALL THE COPYRIGHT OWNER OR CONTRIBUTORS BE
   LIABLE FOR ANY DIRECT, INDIRECT, INCIDENTAL, SPECIAL, EXEMPLARY, OR
   CONSEQUENTIAL DAMAGES (INCLUDING, BUT NOT LIMITED TO, PROCUREMENT OF
   SUBSTITUTE GOODS OR SERVICES; LOSS OF USE, DATA, OR PROFITS; OR BUSINESS
   INTERRUPTION) HOWEVER CAUSED AND ON ANY THEORY OF LIABILITY, WHETHER IN
   CONTRACT, STRICT LIABILITY, OR TORT (INCLUDING NEGLIGENCE OR OTHERWISE)
   ARISING IN ANY WAY OUT OF THE USE OF THIS SOFTWARE, EVEN IF ADVISED OF THE
   POSSIBILITY OF SUCH DAMAGE. */

/* $Id$ */
/**
 * @file
 * @brief Dresden Elektronik Radio Module deRFmega128-22A001
 *
 *
 *
<pre>

Fuses/Locks:
     LF: 0xe2 - 8MHz internal RC Osc.
     HF: 0x11 - without boot loader
     HF: 0x10 - with boot loader
     EF: 0xff
     LOCK: 0xef - protection of boot section

Bootloader:
    Start at byte=0x1e000, address=0xf000, size = 4096 instructions/ 8192 bytes


radiofaro:
  LEDS: PG1, PG2

</pre>


@par Build Options

  - derfa1 : Radio Module deRFmega128-22A001

  - radiofaro : wireless Ardino board
  - radiofaro_v1 : wireless Ardino board

  - zigduino : Logos Electromechanical LLC
               http://www.logos-electro.com/blog/2010/5/16/zigduino.html
  - pinoccio : http://pinocc.io/
  - raspbee : Dresden Electronic Raspberry Pi Modul.
  - derfn256u0, derfn256u0, derfn128u0:
              Dresden Electronic deRFNode w/ UART0 (header X5)
  - derfn128: Dresden Electronic deRFNode w/ USB

 */

#ifndef BOARD_DERFA_H
#define BOARD_DERFA_H

#if defined(derfa1)
# define BOARD_TYPE BOARD_DERFA1
# define BOARD_NAME "derfa1"
#define RADIO_TYPE (RADIO_ATMEGA128RFA1_C)
#elif defined(radiofaro)
# define BOARD_TYPE BOARD_RADIOFARO
# define BOARD_NAME "radiofaro"
#define RADIO_TYPE (RADIO_ATMEGA128RFA1_D)
#elif defined(radiofaro_v1)
# define BOARD_TYPE BOARD_RADIOFARO_V1
# define BOARD_NAME "radiofaro v1"
#define RADIO_TYPE (RADIO_ATMEGA128RFA1_C)
#elif defined(zigduino)
# define BOARD_TYPE BOARD_ZIGDUINO
# define BOARD_NAME "zigduino"
#define RADIO_TYPE (RADIO_ATMEGA128RFA1_C)
#elif defined(xxo)
# define BOARD_TYPE BOARD_XXO
# define BOARD_NAME "tic_tac_toe"
#define RADIO_TYPE (RADIO_ATMEGA128RFA1_C)
#elif defined(wprog)
# define BOARD_TYPE BOARD_WPROG
# define BOARD_NAME "wprog"
# define RADIO_TYPE (RADIO_ATMEGA128RFA1_D)
#elif defined(pinoccio)
# define BOARD_TYPE BOARD_PINOCCIO
# define BOARD_NAME "pinoccio"
# define RADIO_TYPE (RADIO_ATMEGA256RFR2)
#elif defined(raspbee)
# define BOARD_TYPE BOARD_RASPBEE
# define BOARD_NAME "raspbee"
# define RADIO_TYPE (RADIO_ATMEGA256RFR2)
#elif defined(derfn256u0)
# define BOARD_TYPE BOARD_DERFN256U0
# define BOARD_NAME "derfn256u0"
# define RADIO_TYPE (RADIO_ATMEGA256RFR2)
#elif defined(derfn256u0pa)
# define BOARD_TYPE BOARD_DERFN256U0PA
# define BOARD_NAME "derfn256u0pa"
# define RADIO_TYPE (RADIO_ATMEGA256RFR2)
#elif defined(derfn128)
# define BOARD_TYPE BOARD_DERFN128
# define BOARD_NAME "derfn128"
# define RADIO_TYPE (RADIO_ATMEGA128RFA1_D)
#elif defined(derfn128u0)
# define BOARD_TYPE BOARD_DERFN128U0
# define BOARD_NAME "derfn128u0"
# define RADIO_TYPE (RADIO_ATMEGA128RFA1_D)
#endif
/*=== Compile time parameters ========================================*/

/*=== Hardware Components ============================================*/

/** timestamp register for RX_START event */
#define TRX_TSTAMP_REG TCNT1

#if BOARD_TYPE == BOARD_RADIOFARO
# define LED_PORT      PORTG
# define LED_DDR       DDRG
# define LED_MASK      (0x06)
# define LED_SHIFT     (1)
# define LEDS_INVERSE  (0)
# define LED_NUMBER    (2)
#elif BOARD_TYPE == BOARD_WPROG
# define LED_PORT      PORTD
# define LED_DDR       DDRD
# define LED_MASK      (0x40)
# define LED_SHIFT     (6)
# define LEDS_INVERSE  (1)
# define LED_NUMBER    (1)
#elif BOARD_TYPE == BOARD_PINOCCIO
# define LED_PORT      PORTB
# define LED_DDR       DDRB
# define LED_MASK      (0x70)
# define LED_SHIFT     (4)
# define LEDS_INVERSE  (1)
# define LED_NUMBER    (3)
#elif BOARD_TYPE == BOARD_XXO

/* We just define the first three LEDs in row 1
 * use a special display driver, that is frequently
 * updated to handle the full LED matrix.
 */

#define LED_INIT() \
    do {\
        DDRB |= (_BV(PB0) | _BV(PB1) | _BV(PB2) | _BV(PB3));\
        PORTB |= (_BV(PB0) | _BV(PB1) | _BV(PB2) | _BV(PB3));\
    } while(0)


#define LED_SET(x) \
  switch (x) { \
  case 0: PORTB &= ~_BV(0); break; \
  case 1: PORTB &= ~_BV(1); break; \
  case 2: PORTB &= ~_BV(2); break; \
  }

#define LED_CLR(x) \
  switch (x) { \
  case 0: PORTB |= _BV(0); break; \
  case 1: PORTB |= _BV(1); break; \
  case 2: PORTB |= _BV(2); break; \
  }
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

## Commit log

2012-10-04 Initial import
    [bom.xls, pinoccio.brd, pinoccio.sch]
2012-10-04 Update licensing on eagle files
    [pinoccio.brd, pinoccio.sch]
2012-10-04 Add back hidden layers
    [pinoccio.brd]
2012-10-04 Updated description on board file
    [pinoccio.brd]
2012-10-04 Removed D1 LED for power--for better power handling. Instead, will modify the bootloader to flash the bicolor LED a couple times upon power up, then turn off. Thanks Louis for the idea!
    [pinoccio.brd, pinoccio.sch]
2012-10-05 Clean up bottom silkscreen
    [pinoccio.brd]
2012-10-05 Add a couple more ground vias to minimize impedance
    [pinoccio.brd]
2012-10-05 Updated bicolor LED values to a more sane value. Add 0603 landing pattern for Lipo IC charge current capacity (for people to mod if they want higher C-ratings). Fix mosfet reversal error. (Thanks Mon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
    [bom.xls, pinoccio.brd, pinoccio.sch]
2012-10-05 Updated datasheet to dual package transistor.
    [pinoccio.brd, pinoccio.sch]
2012-10-08 Update package for right-angle switch, make minor changes as recommended in Atmel App Note AVR2044
    [pinoccio.brd, pinoccio.sch]
2012-10-08 Moar ground routing/vias to decrease any possible inductance
    [pinoccio.brd]
2012-10-09 Updated pinoccio copper/mask logo
    [pinoccio.brd]
2012-10-30 Version 0.6
    [pinoccio.brd, pinoccio.sch]
2012-11-02 Update to latest v0.6
    [pinoccio.brd, pinoccio.sch]
2012-11-03 Updated rfa1 with PWM and interrupt notes
    [pinoccio.sch]
2012-11-07 More board updates
    [pinoccio.brd]
2012-11-28 more cleanups
    [pinoccio.brd, pinoccio.sch]
2012-12-05 Updated to v0.7
    [pinoccio.brd, pinoccio.sch]
2012-12-15 Update to v0.9 for lower power regulator, replace MOSFET with dual switch, and other cleanups
    [pinoccio.brd, pinoccio.sch]
2012-12-15 remove outdated bom
    [bom.xls]
2012-12-15 Update to v0.9
    [pinoccio.brd, pinoccio.sch]
2012-12-17 Change up header socket pins for better scatter cable adapter support
    [pinoccio.brd, pinoccio.sch]
2012-12-18 Fix up more minor tweaks
    [pinoccio.brd]
2012-12-24 Clean up extra lines
    [pinoccio.brd]
2012-12-26 Fix changes needed for reset pullup resistor for 16U2
    [pinoccio.brd, pinoccio.sch]
2012-12-26 Update changes file
    [pinoccio.brd]
2012-12-28 re-cleaned up reset line to 16U2
    [pinoccio.brd, pinoccio.sch]
2012-12-29 Added new socker header datasheet
    [pinoccio.brd, pinoccio.sch]
2013-01-01 Moar fixups
    [pinoccio.brd, pinoccio.sch]
2013-01-03 Fix up library naming
    [pinoccio.brd, pinoccio.sch]
2013-01-04 move charge LED anode side to vbat instead of vusb
    [pinoccio.brd, pinoccio.sch]
2013-01-04 Adjust a couple of spacing issues
    [pinoccio.brd, pinoccio.sch]
2013-01-07 More minor silkscreen updates
    [pinoccio.brd]
2013-01-16 Tagging for v0.9
    [pinoccio.brd, pinoccio.sch]
2013-03-30 v0.10 update
    [pinoccio.brd, pinoccio.sch]
2013-04-01 Add addl contributors, and swap dual load switch for single load switch
    [pinoccio.brd, pinoccio.sch]
2013-04-13 version 0.11 updates
    [pinoccio.brd, pinoccio.sch]
2013-04-26 Fix wrong value for pull-down on mosfet
    [pinoccio.brd, pinoccio.sch]
2013-04-28 more v0.11 changes
    [pinoccio.brd, pinoccio.sch]
2013-07-07 v0.12 changes
    [pinoccio.brd, pinoccio.sch]
2013-07-12 Add resistor change to pulldown
    [pinoccio.brd, pinoccio.sch]
2013-07-13 version 0.13
    [pinoccio.brd, pinoccio.sch]
2013-07-16 v0.13 changes
    [pinoccio.brd]
2013-07-16 Minor schematic tweak
    [pinoccio.sch]
2013-07-19 update pi network components
    [pinoccio.brd, pinoccio.sch]
2013-09-24 updated names of components for assembly
    [pinoccio.brd, pinoccio.sch]
2013-11-20 Updated PDF version of schematic
2014-02-26 Add atmega16u2 firmware
    This is the firmware that runs on the 16u2 that does USB->serial
    conversion on the Pinoccio Scout. This firmware was previously stored in
    the piniccio-firmware / core-pinoccio repository, but it is more at
    place here.
    [ConfiguringApps.txt]
2014-07-03 Add BOM and labels for jumpers
    [pinoccio.brd, pinoccio.sch]
2015-03-06 dissector: Add Wireshark dissector for p2p / wibo packets
    This allows dissecting captured packets exchanged with the bootloader
    using Wireshark. This file is taken from uracoli-sniffer-0.4.2.zip
    unmodified.
    This file is licensed under the modified BSD license. The text for the
    license will be added to the file next.
2015-03-06 dissector: Update the recent protocol version
    The dissector still assumed an early version of the protocol, which was
    changed somewhere during 2012. This updates the dissector to a newer
    version of the protocol.
    This makes the following changes:
    - Remove channel sweep packets
    - Add Wibo set target, deaf and set address commands
    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
2015-03-06 dissector: Simplify parsing by using a sub-buffer
    The wireshark Tvb class allows creating virtual sub-buffers, so we can
    just pass a buffer with just the packet payload to the parsing
    functions, instead of the original buffer and an offset.
2015-03-06 dissector: Don't bother dissecting 802.15.4 fields
    Wireshark can already do this, so no need to have them displayed twice.
2015-03-06 dissector: Restructure parsing
    Instead of registering as a postdissector that gets run on all
    (complete) packets, we register as both a normal and heuristic
    dissector for wpan packets. This means we'll only get called for
    802.15.4 packets, that do not have a packet type manually set (using
    "Decode as...").
    This also means the buffer we get passed only contains the 802.15.4 data
    payload, so we adapt the code to that. This does mean we can no longer
    check the fcf field (we should be able to access all individual bits
    using fields, but accessing the complete fcf field seems to be
    impossible.
    Some additional checking is added, to make sure we don't set the
    protocol column to "P2P" for packets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
    [p2p-wireshark-dissector.lua]
2015-03-06 dissector: Handle "Range is out of bounds" errors
    When a packet is shorter than expected, the tvb class raises this error.
    By splitting the main dissector function and using pcall, we can capture
    this error and add an appropriate expert info error message.
    [p2p-wireshark-dissector.lua]
2015-03-06 dissector: Simplify registration of ProtoFields
    Instead of creating them as a pile of local variables and adding them to
    p2p.fields later, just create them as members of p2p.fields directly.
    Apparently the Wireshark Lua bindings contain some magic to allow this.
    [p2p-wireshark-dissector.lua]
2015-03-06 dissector: Add error message when packet is too long
    [p2p-wireshark-dissector.lua]
2015-03-06 dissector: Fix boardname length
    It was previously changed to take 16 characters, but it actually takes
    up the remainder of the packet.
    [p2p-wireshark-dissector.lua]
2015-03-06 dissector: Fix heuristic return value
    It turns out calling p2p.dissector always returns nil, so the previous
    lambda workaround does not apply. Now we just keep the dissector
    function around as a normal function, so we can pass it to
    register_heuristic directly.
    [p2p-wireshark-dissector.lua]
2015-03-06 dissector: Fix endianness of set address command
    [p2p-wireshark-dissector.lua]
2015-03-06 bootloader: Make debug output from wibo.c work
    Before, this tried to use some "hif" I/O abstraction, probably from
    uracoli, while main.c already set up the UART. This commit makes wibo.c
    use the sendchar function defined in main.c already.
    Debug output is disabled by default, it needs -D_DEBUG_SERIAL to be
    passed while compiling to work.
2015-03-06 Remove PDF versions of old schematic and board version
    Instead of keeping all PDF versions, we'll just add them for specific
    git tags.
2015-03-06 16u2: Remove Arduino-usbserial-noreset.c
    This seems like it was a copy of an older version of Arduino-usbserial.c
    that is not used in the build, with autoreset disabled. Best clean it up
    to prevent confusion.
2015-04-17 bootloader: Go to sleep during SPM write operation
    Atmel confirms there is a hardware bug that can, under some unknown set
    of circumstances, overwrite the program counter when writing to the
    second half of the flash on the ATMEGA64/128/256 RFR2 and 4RFR2 family.
    As a workaround, it helps to sleep during the SPM operation (waiting for
    the SPM complete interrupt to wake us up), since the bug requires
    reads from flash to trigger.
    It should only affect flash writes, but this applies the sleep trick to
    page erases as well, just for good measure.
    This fix was originally created by Geoff and improved by Matthijs.
    [main.c]

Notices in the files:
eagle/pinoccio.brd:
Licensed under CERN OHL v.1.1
